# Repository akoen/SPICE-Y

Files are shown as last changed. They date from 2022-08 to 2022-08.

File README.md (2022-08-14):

# SPICE-Y: 2nd Place 2022 ENPH 253 Competition Robot 

  





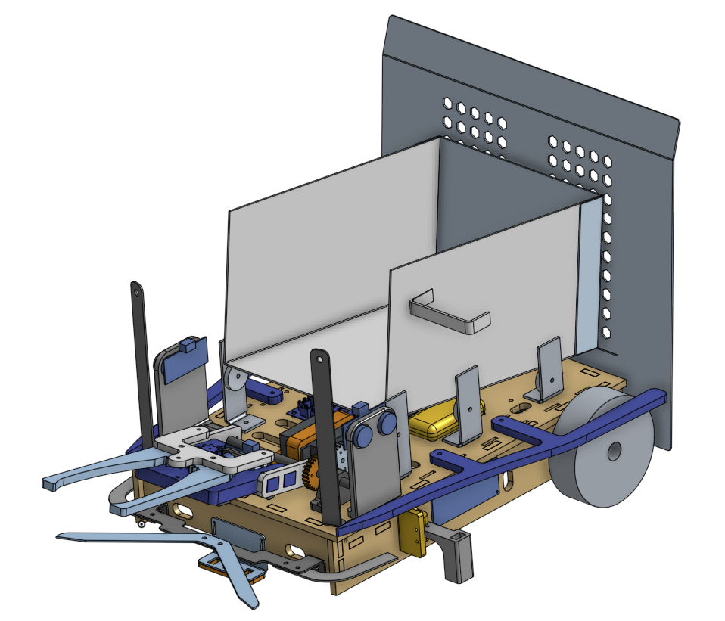
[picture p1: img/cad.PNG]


## Overview & Highlights
- Built on the STM32F103 platform with the [stm32duino](https://github.com/stm32duino/Arduino_Core_STM32) library
- High-data rate ADC sampling (~100 kHz) using direct memory access (DMA) to Fourier decompose infrared beacon signals
- Custom [PCBs](https://github.com/akoen/SPICEBot/blob/main/pcbs/SPICEBot.pdf) for motor drivers, reflectance sensors, mainboard distribution
- Mechanical design done in [Onshape](https://cad.onshape.com/documents/5972b9c60e919ab1b13b074c/w/5fe346639d96b627bb4d7038/e/e34fbf874ea22aab1deaf443)

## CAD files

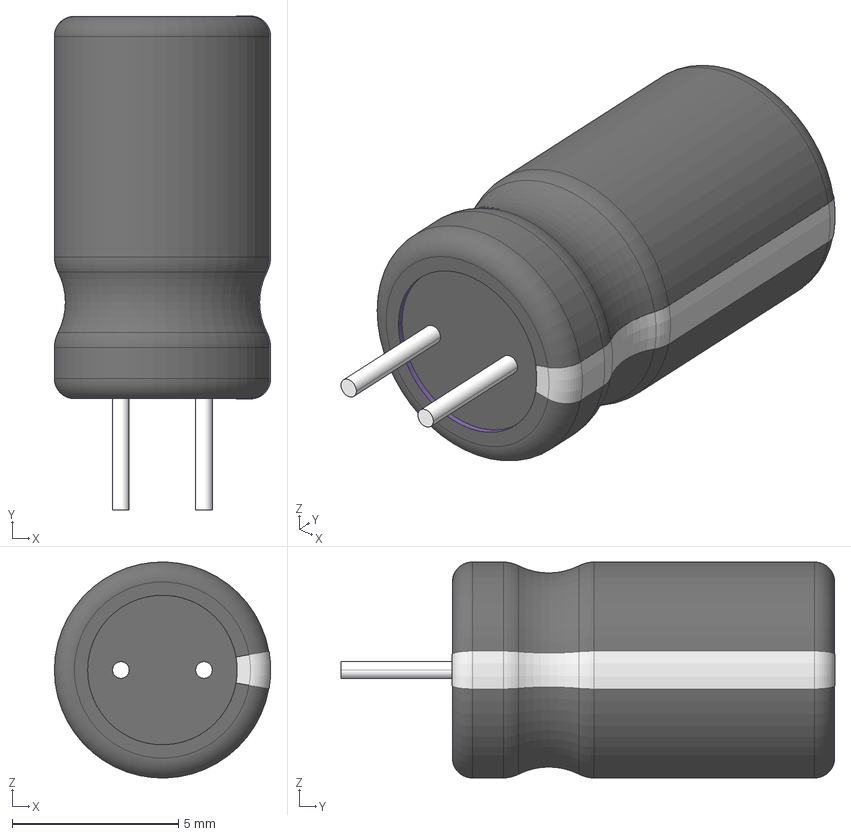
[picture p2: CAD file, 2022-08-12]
pcbs/3D Models/cpol-v_p2-5_d6-5_h11-5.stp
6.50 x 14.9 x 6.50 mm

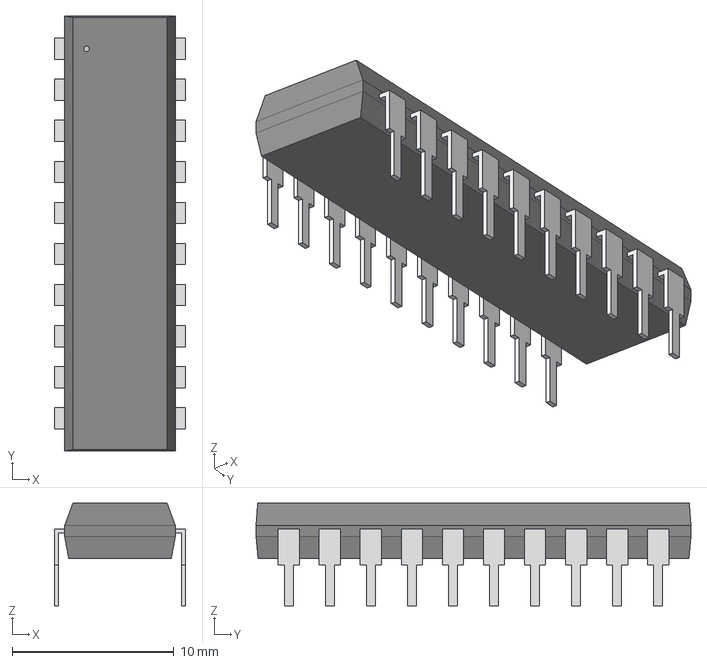
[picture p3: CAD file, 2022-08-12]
pcbs/3D Models/PDIP-20_N_LIT.step
8.13 x 26.9 x 6.35 mm

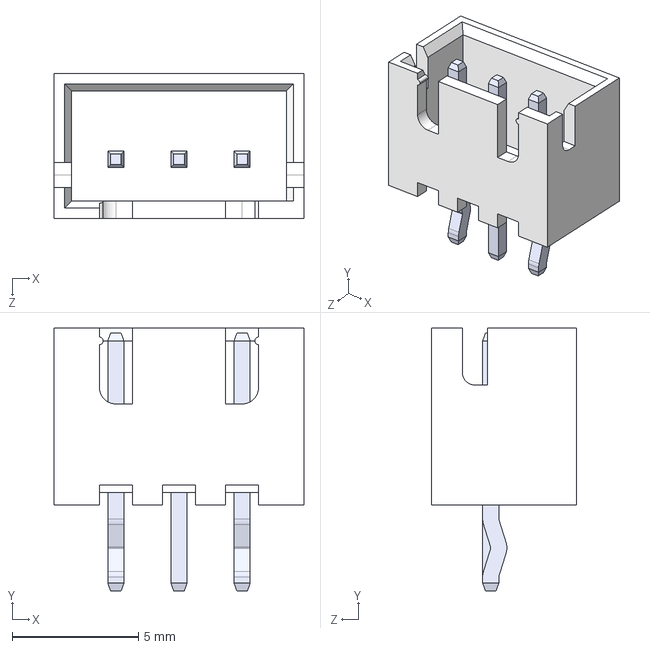
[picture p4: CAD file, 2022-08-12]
pcbs/3D Models/B3B-XH-A-LF--SN---3DModel-STEP-418109.STEP
9.90 x 10.4 x 5.75 mm

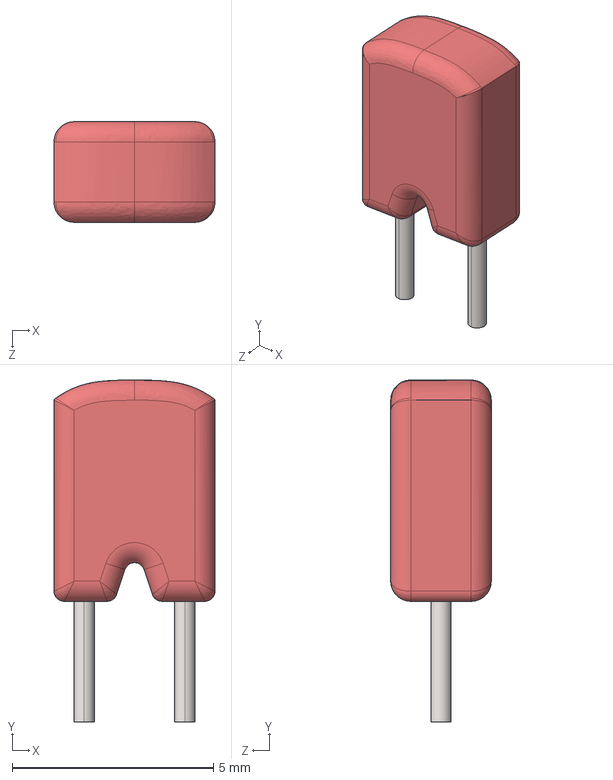
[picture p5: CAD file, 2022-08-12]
pcbs/3D Models/User Library-K104M15X7RF53L2.STEP
4.00 x 8.50 x 2.50 mm

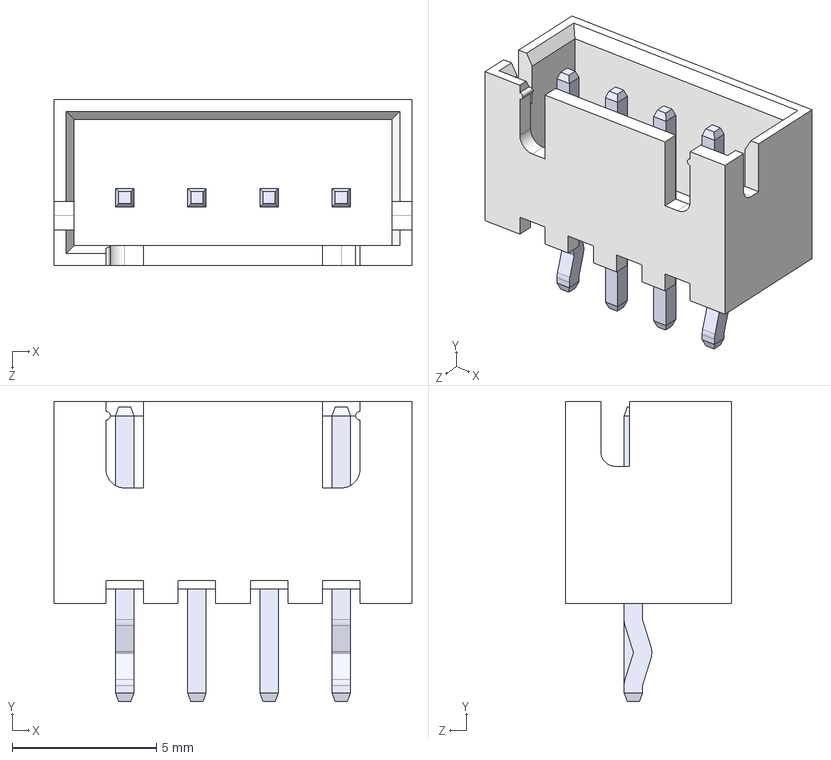
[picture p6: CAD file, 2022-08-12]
pcbs/3D Models/B4B-XH-A-LF--SN---3DModel-STEP-418109.STEP
12.4 x 10.4 x 5.75 mm

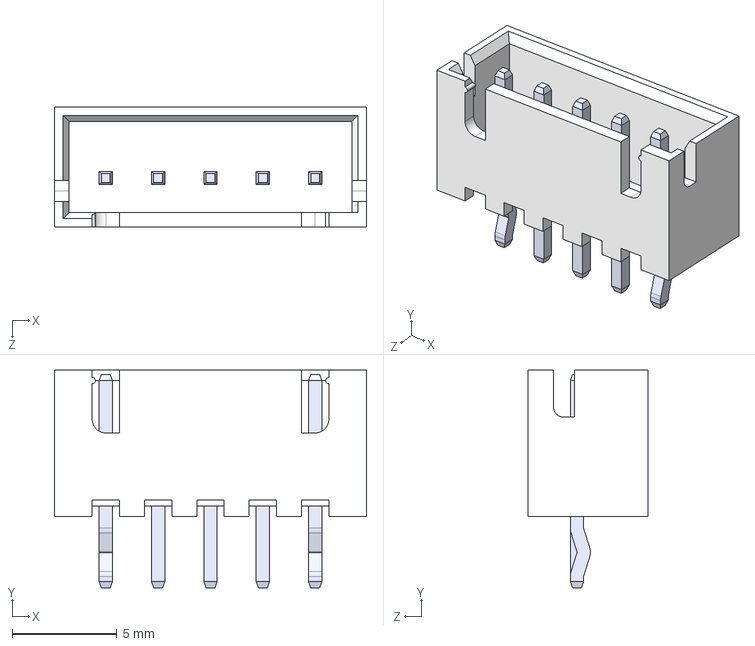
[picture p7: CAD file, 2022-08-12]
pcbs/3D Models/B5B-XH-A-LF--SN---3DModel-STEP-418109.STEP
14.9 x 10.4 x 5.75 mm

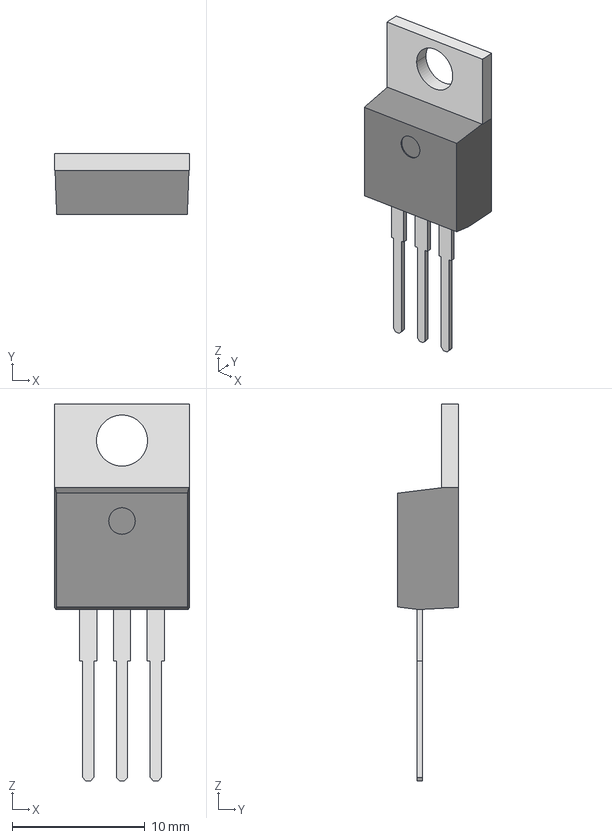
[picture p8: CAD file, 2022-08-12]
pcbs/3D Models/KCS0003B.stp
10.2 x 4.57 x 28.4 mm
BODY-TO-220
LEAD-TO220 x 3
HEATSINK-TO-220

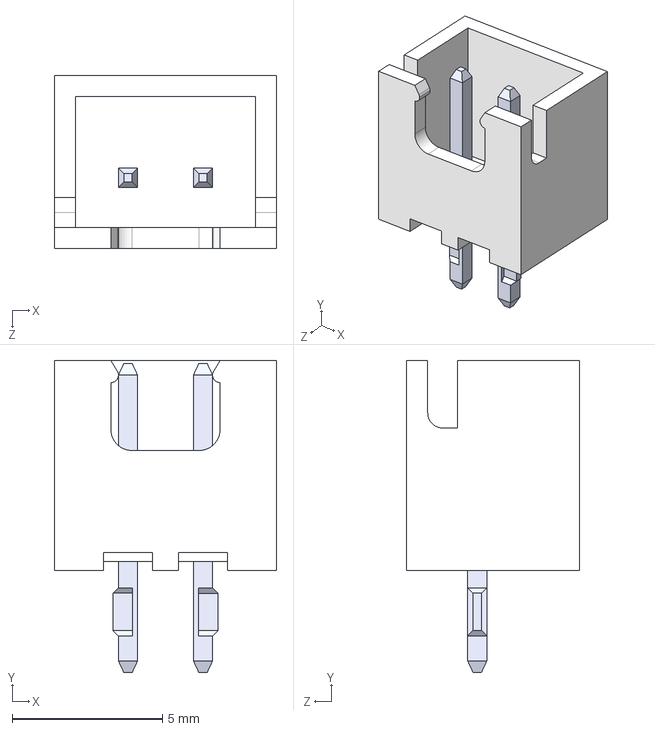
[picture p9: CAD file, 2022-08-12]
pcbs/3D Models/B2B-XH-A-LF--SN---3DModel-STEP-269445.STEP
7.40 x 10.4 x 5.75 mm

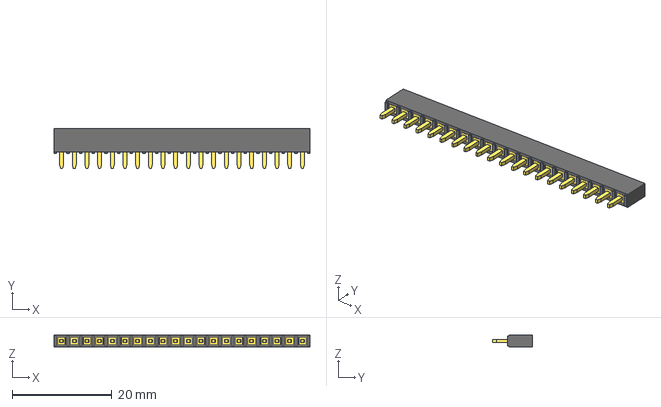
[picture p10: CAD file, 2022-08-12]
pcbs/3D Models/20-Pin Header - Female - 2.54mm.step
51.3 x 8.00 x 2.50 mm

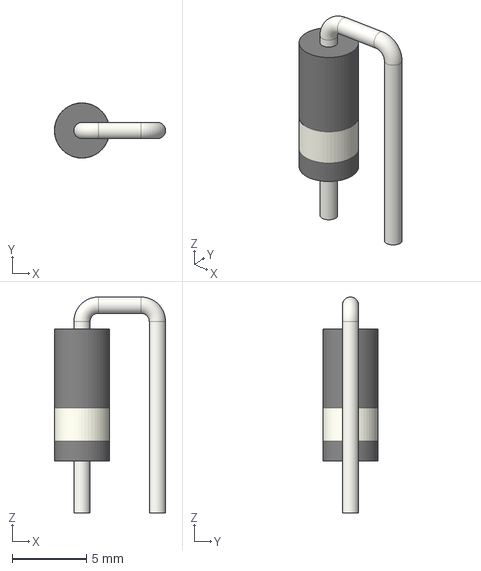
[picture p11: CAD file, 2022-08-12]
pcbs/3D Models/D_5W_P5.08mm_Vertical_AnodeUp.step
7.49 x 3.72 x 14.5 mm

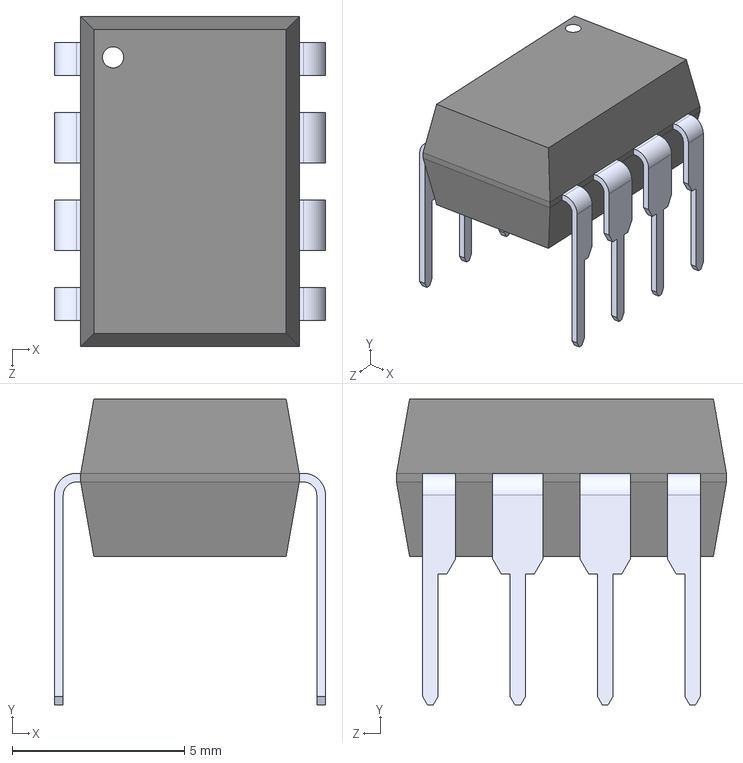
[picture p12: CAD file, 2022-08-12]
pcbs/3D Models/TL082IP.STEP
7.87 x 8.89 x 9.59 mm

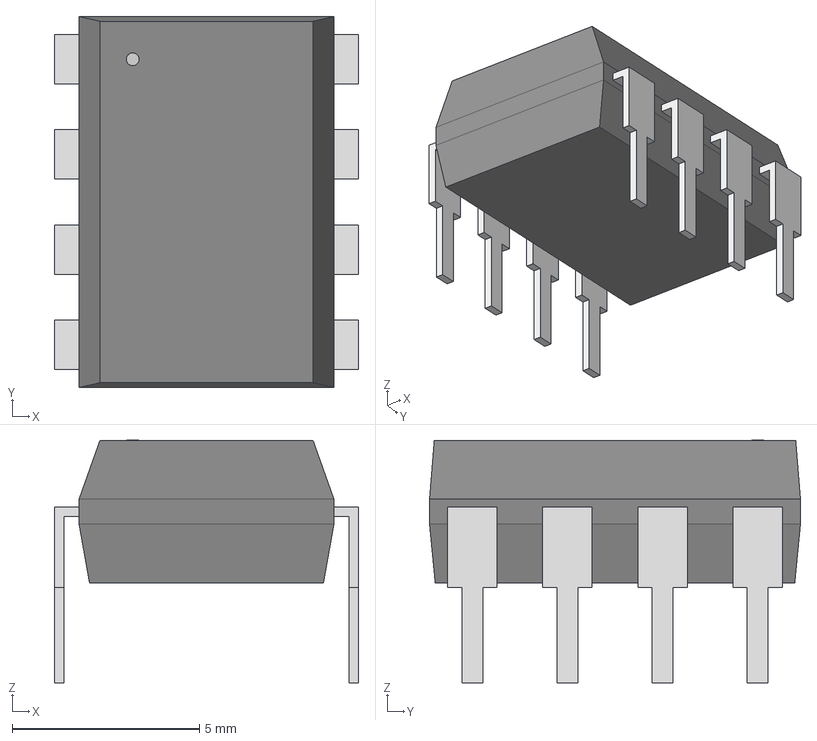
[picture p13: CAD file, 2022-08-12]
pcbs/3D Models/DIP_CT6_VIS.step
8.13 x 9.91 x 6.48 mm

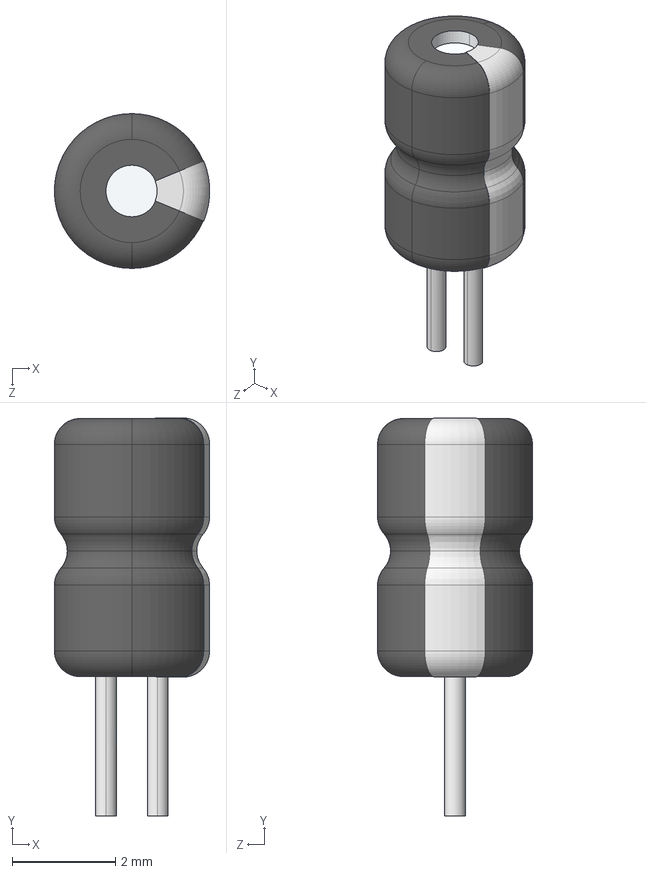
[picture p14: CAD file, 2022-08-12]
pcbs/3D Models/User Library-Capacitor Radial Electrolitic.STEP
3.01 x 7.71 x 3.00 mm

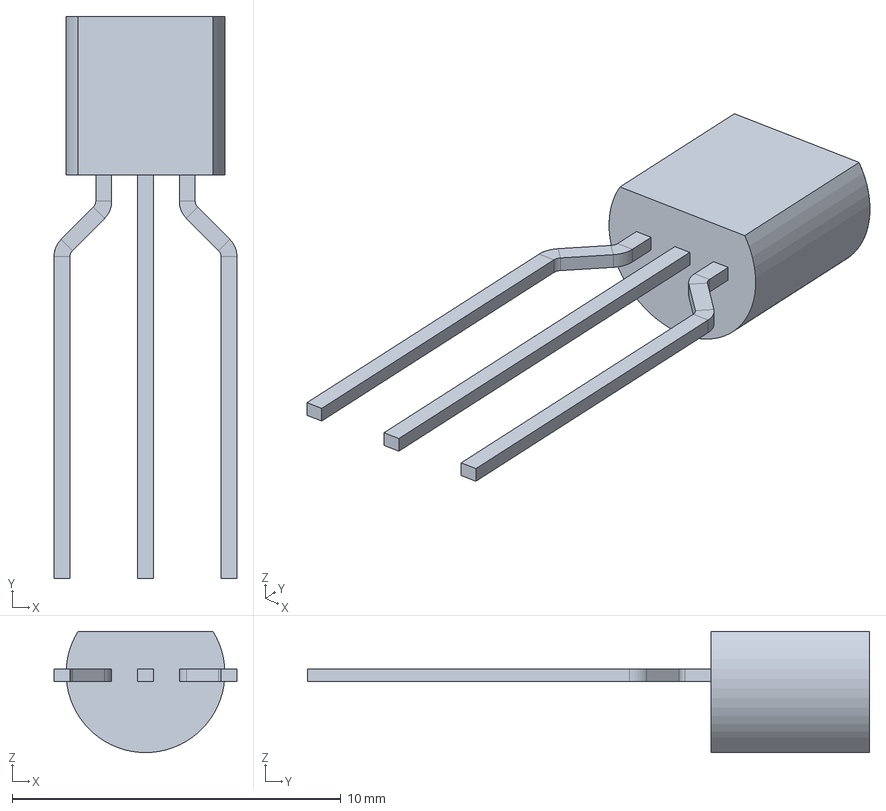
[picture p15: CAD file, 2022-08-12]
pcbs/3D Models/2N2222_1677484790.214.step
5.57 x 17.1 x 3.69 mm
eMachineShop.1
eMachineShop.2
eMachineShop.3
eMachineShop.4
eMachineShop.5
eMachineShop.6
eMachineShop.7
eMachineShop.8
eMachineShop.9
eMachineShop.10
eMachineShop.11
eMachineShop.12
eMachineShop.13
eMachineShop.14
eMachineShop.15
eMachineShop.16
eMachineShop.17
eMachineShop.18
eMachineShop.19
eMachineShop.20
eMachineShop.21
eMachineShop.22
eMachineShop.23
eMachineShop.24
eMachineShop.25
eMachineShop.26
eMachineShop.27
eMachineShop.28
eMachineShop.29
eMachineShop.30
eMachineShop.31
eMachineShop.32
eMachineShop.33
eMachineShop.34
eMachineShop.35
eMachineShop.36
eMachineShop.37
eMachineShop.38
eMachineShop.39
eMachineShop.40
eMachineShop.41
eMachineShop.42
eMachineShop.43
eMachineShop.44
eMachineShop.45
eMachineShop.46
eMachineShop.47
eMachineShop.48
eMachineShop.49
eMachineShop.50
eMachineShop.51
eMachineShop.52
eMachineShop.53
eMachineShop.54
eMachineShop.55

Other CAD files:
pcbs/3D Models/Resistor TH vertical 2,54.stp
pcbs/3D Models/3352T-1-502LF.STEP
pcbs/3D Models/3290W001.stp

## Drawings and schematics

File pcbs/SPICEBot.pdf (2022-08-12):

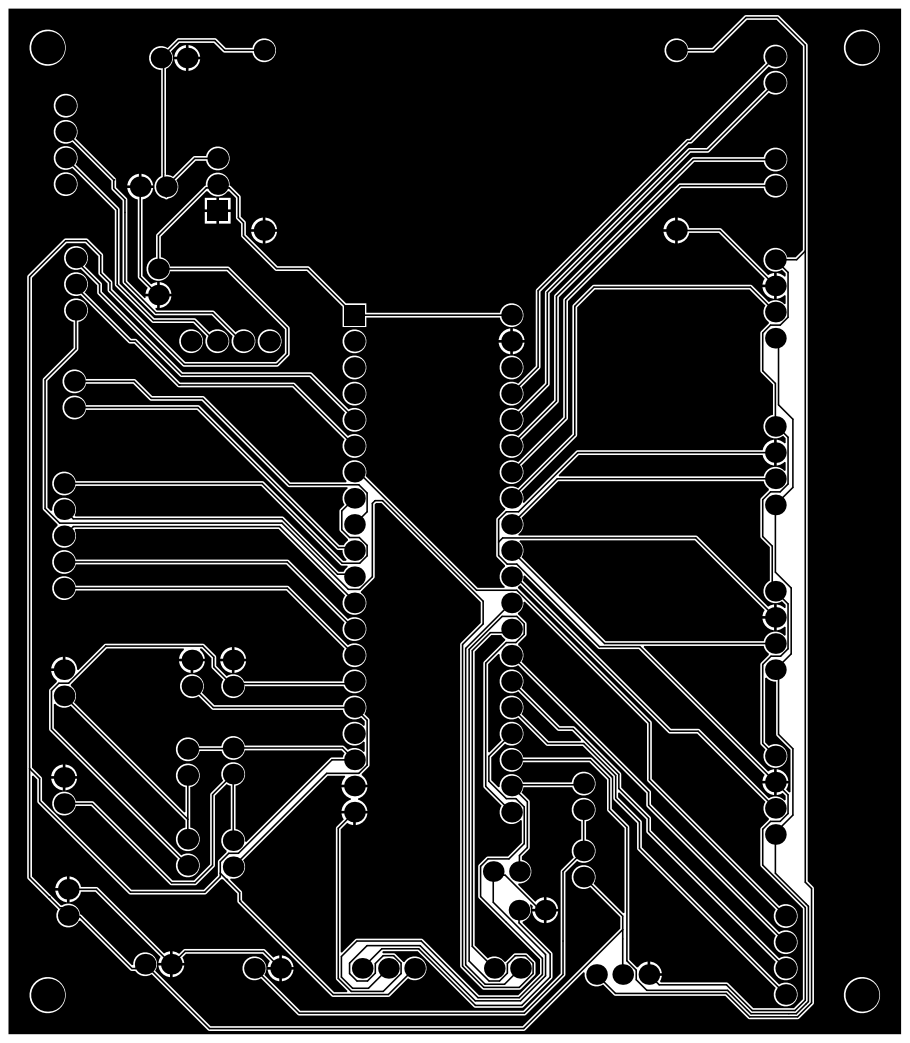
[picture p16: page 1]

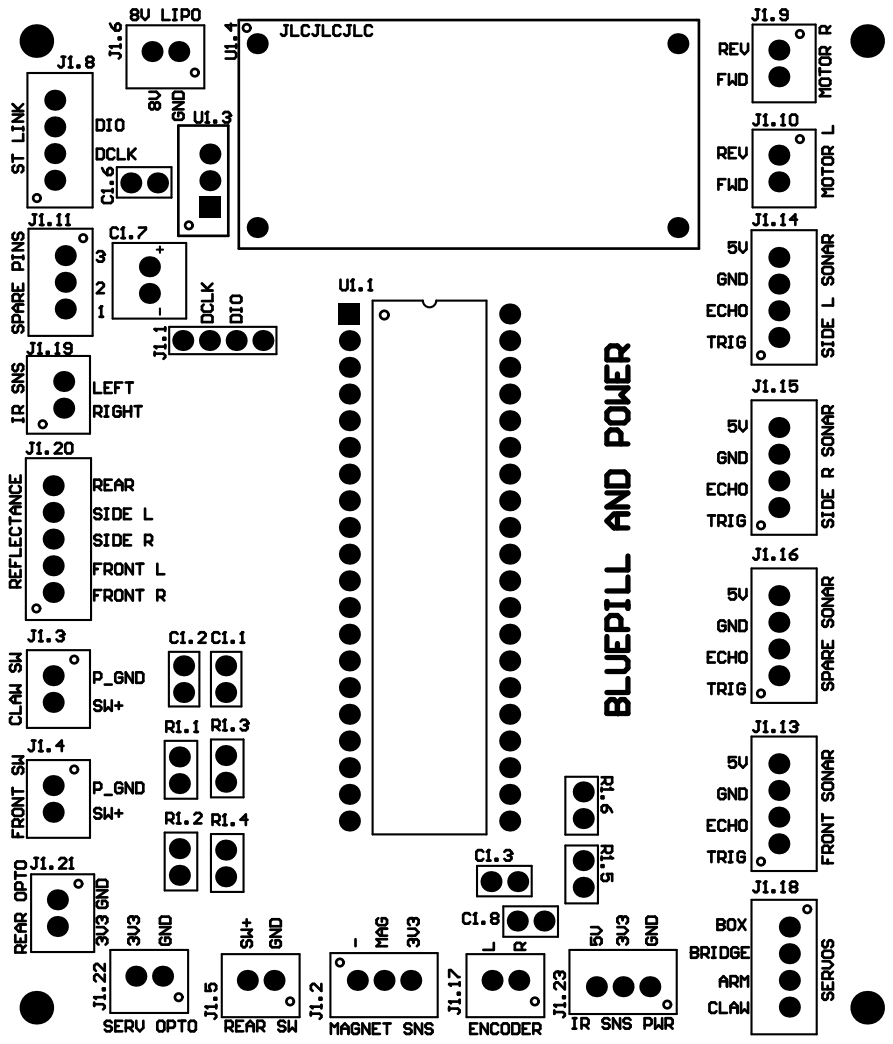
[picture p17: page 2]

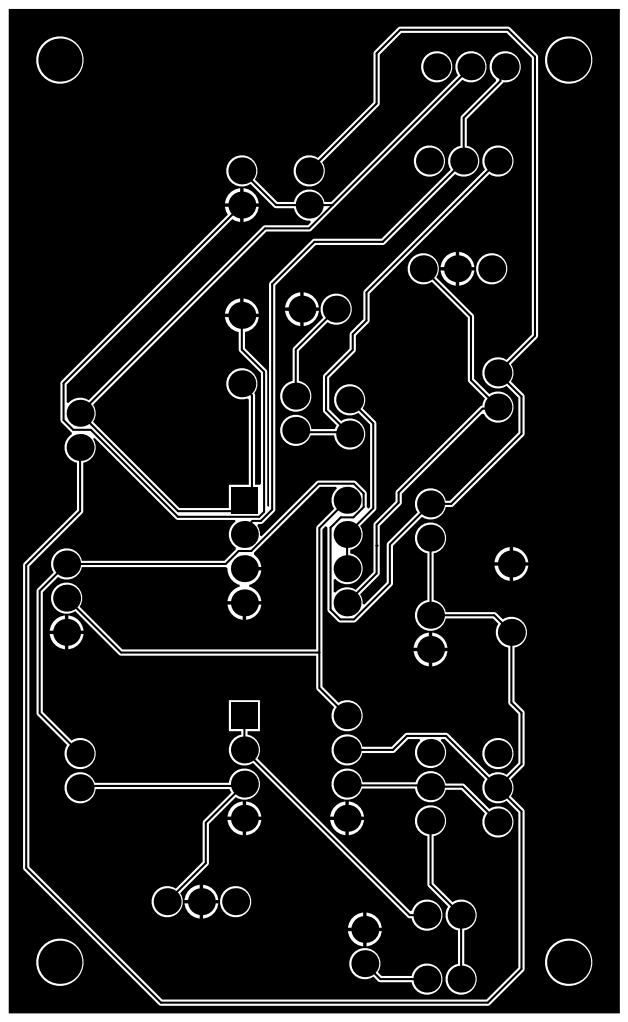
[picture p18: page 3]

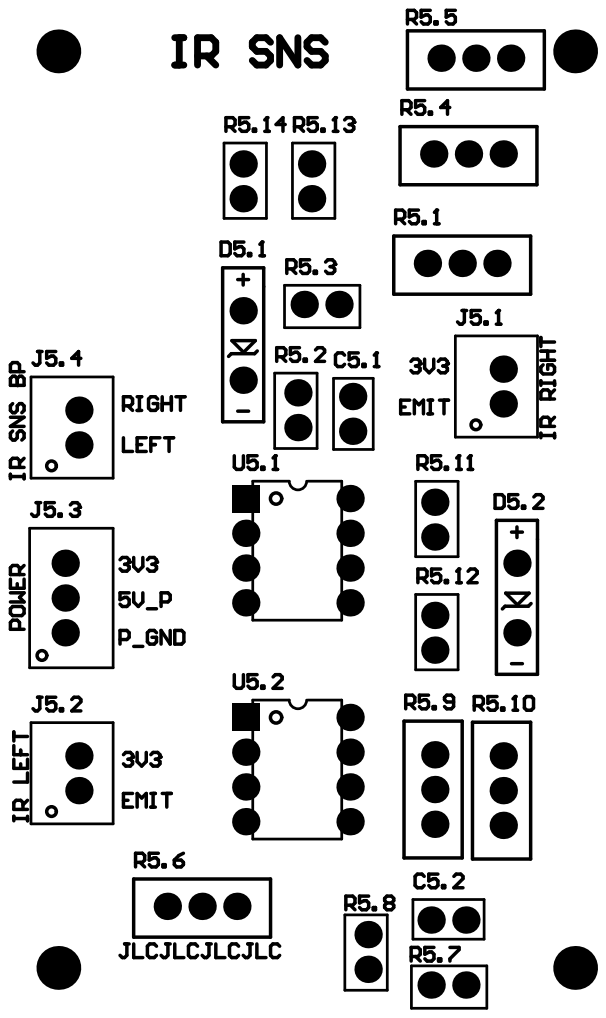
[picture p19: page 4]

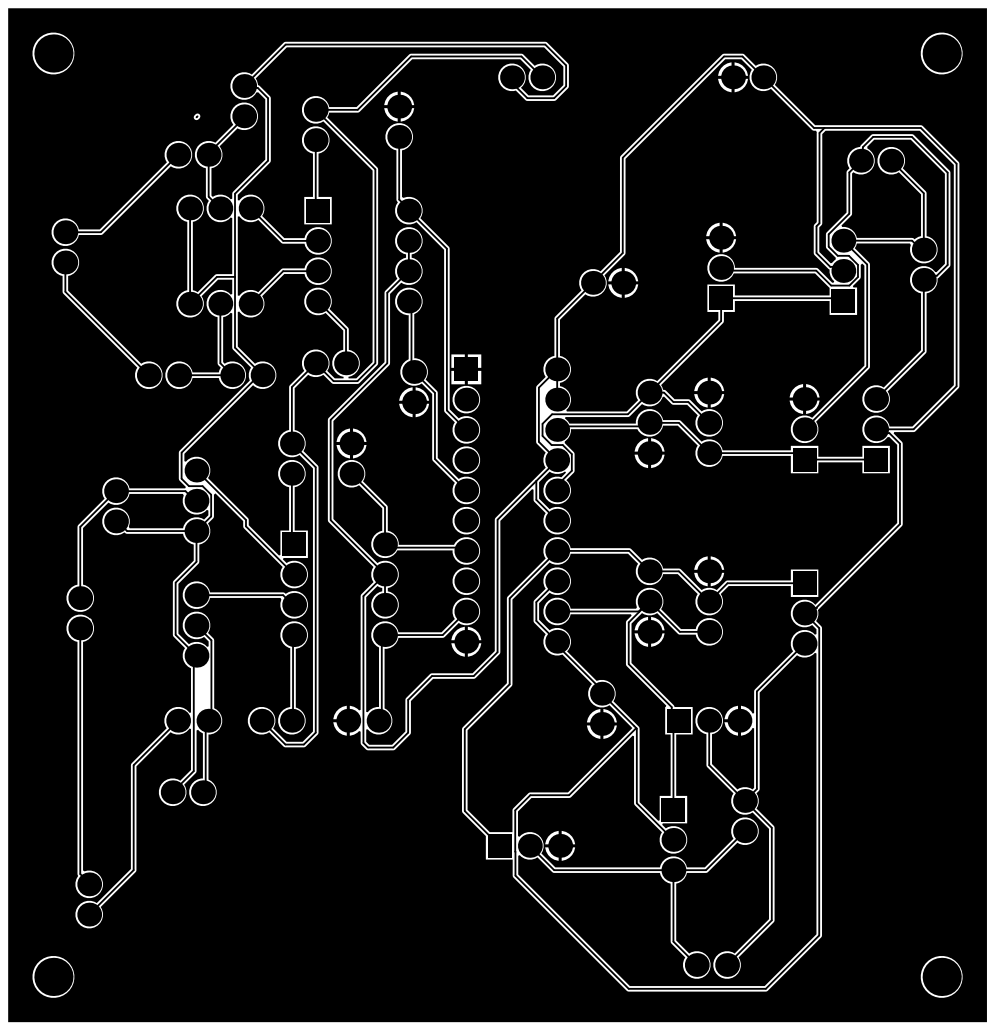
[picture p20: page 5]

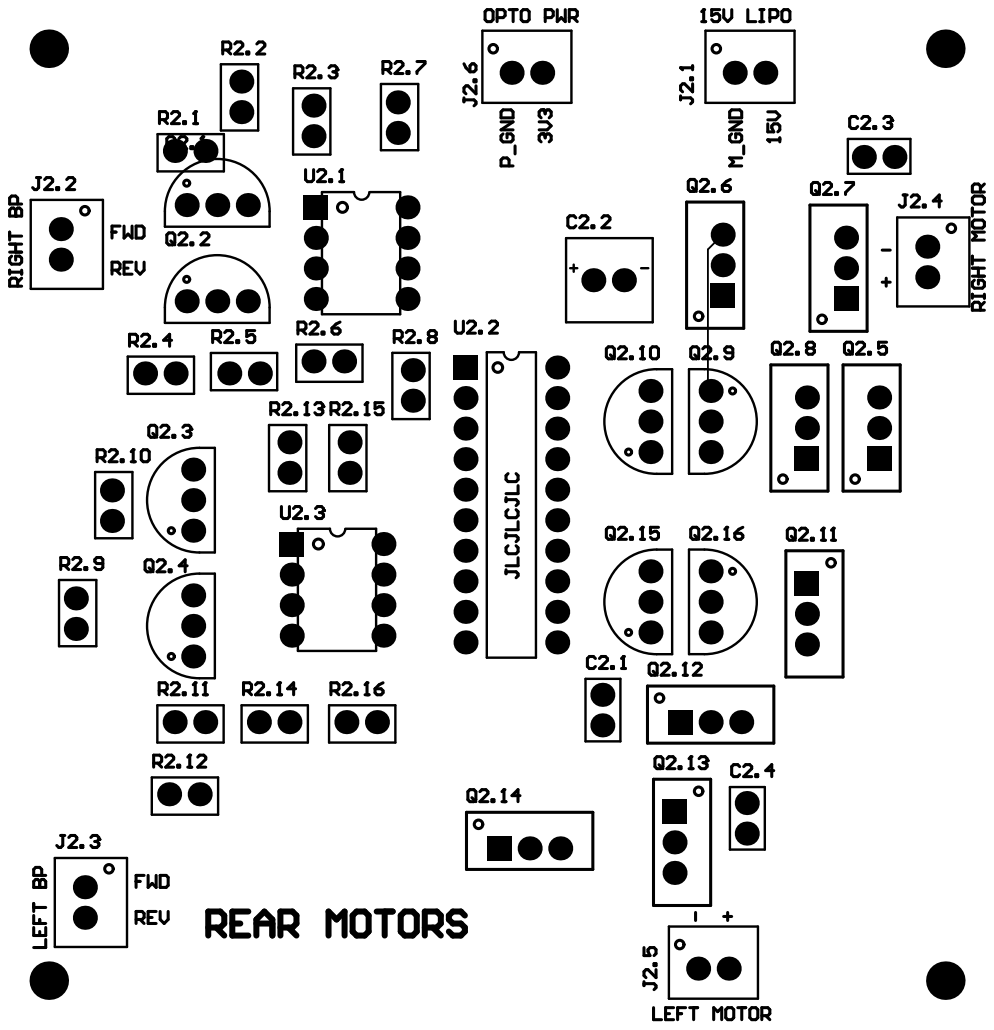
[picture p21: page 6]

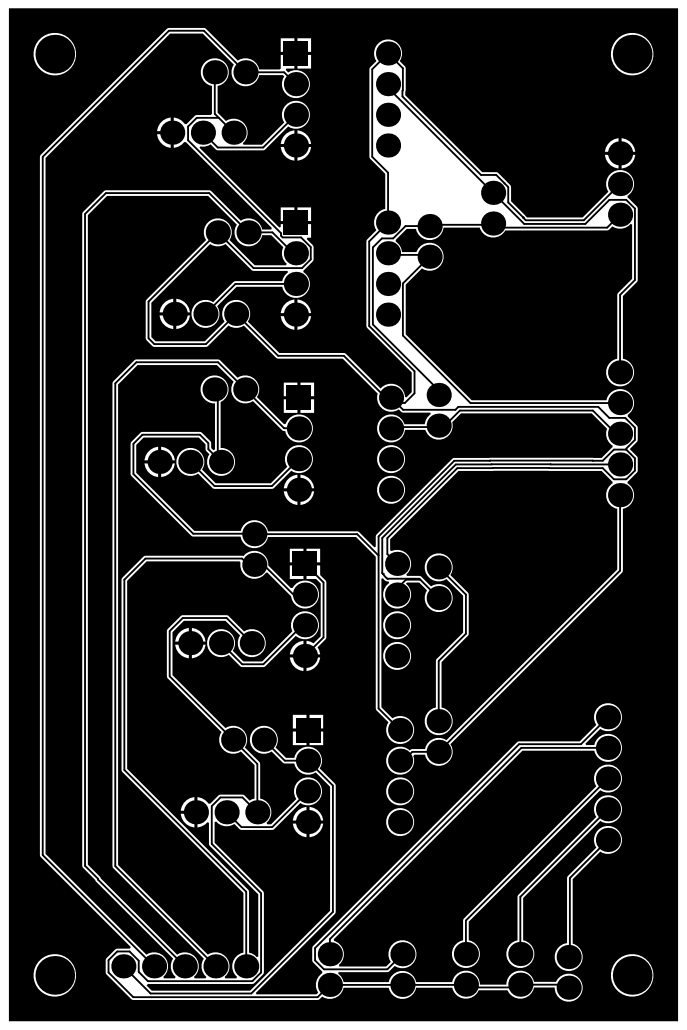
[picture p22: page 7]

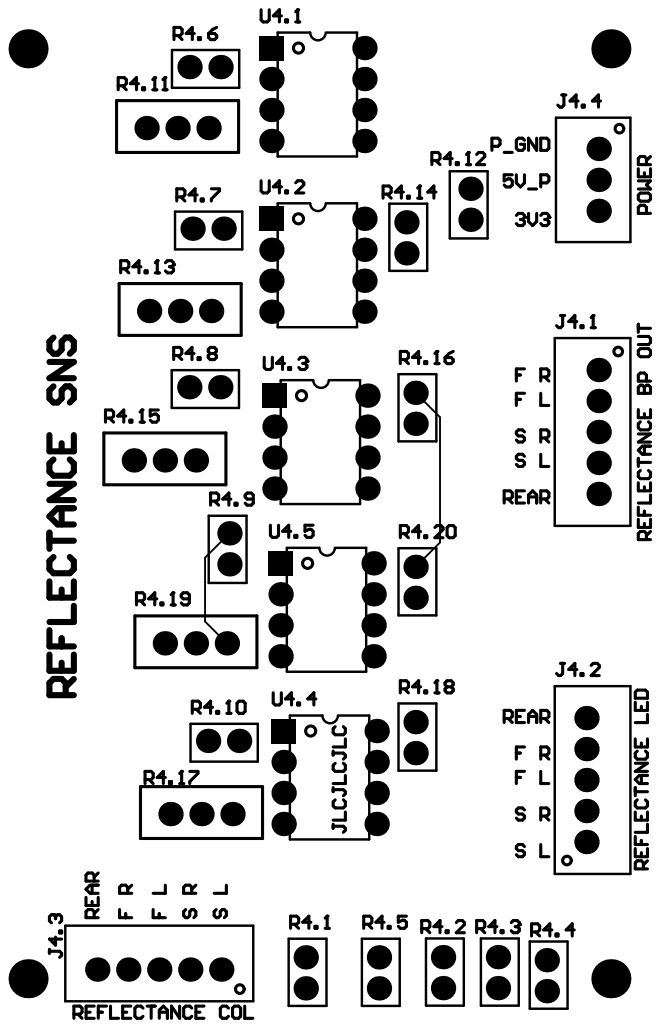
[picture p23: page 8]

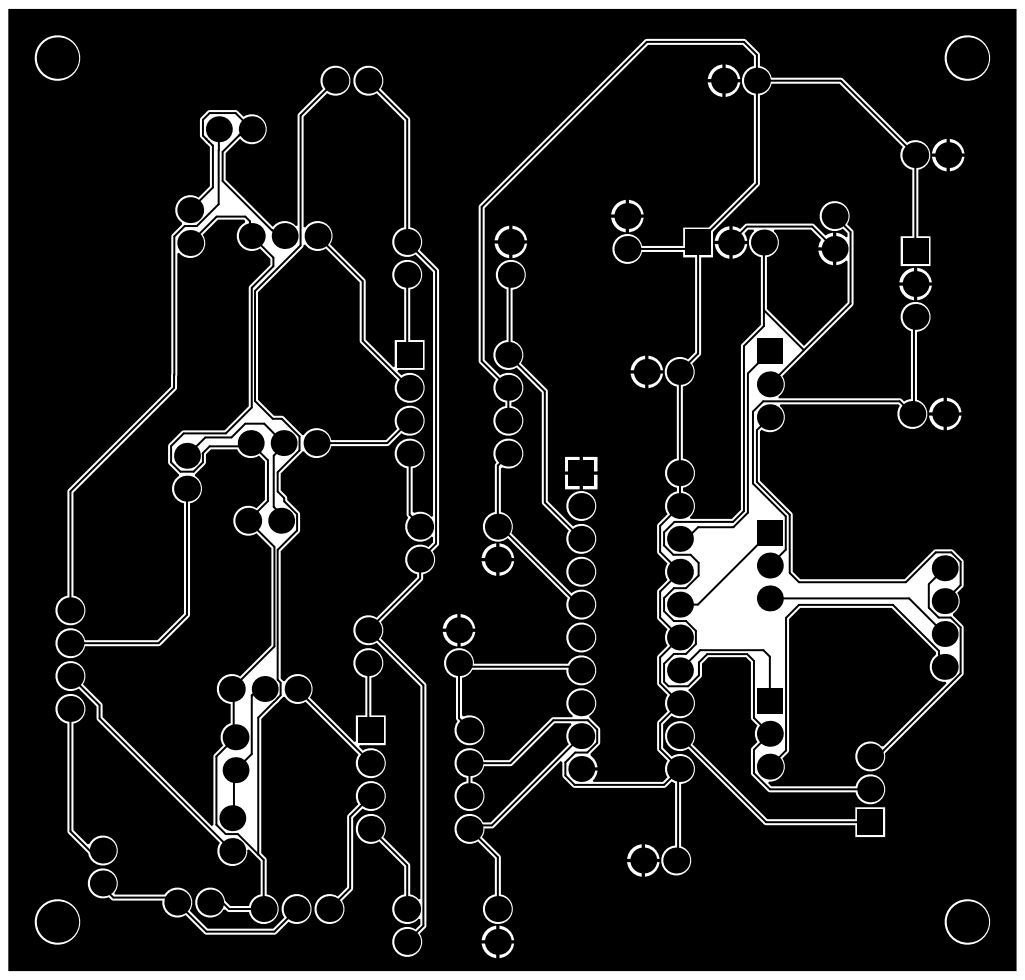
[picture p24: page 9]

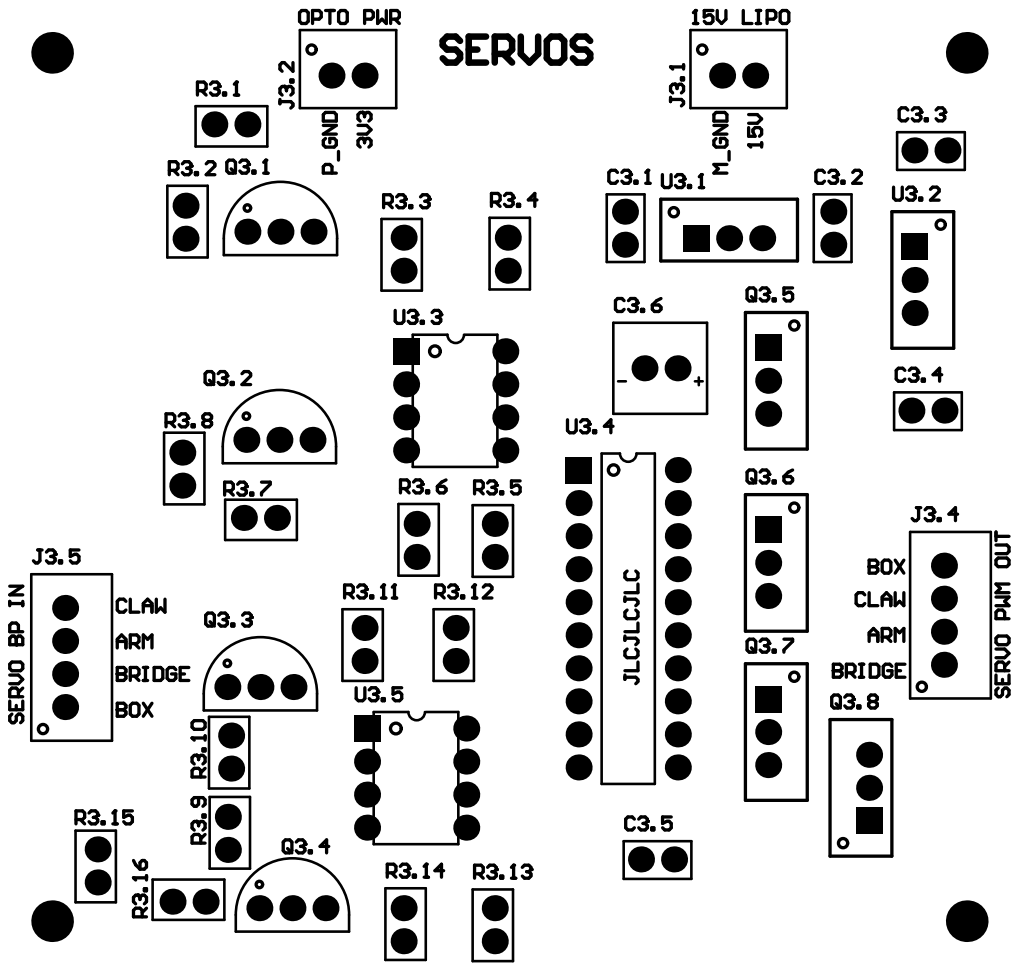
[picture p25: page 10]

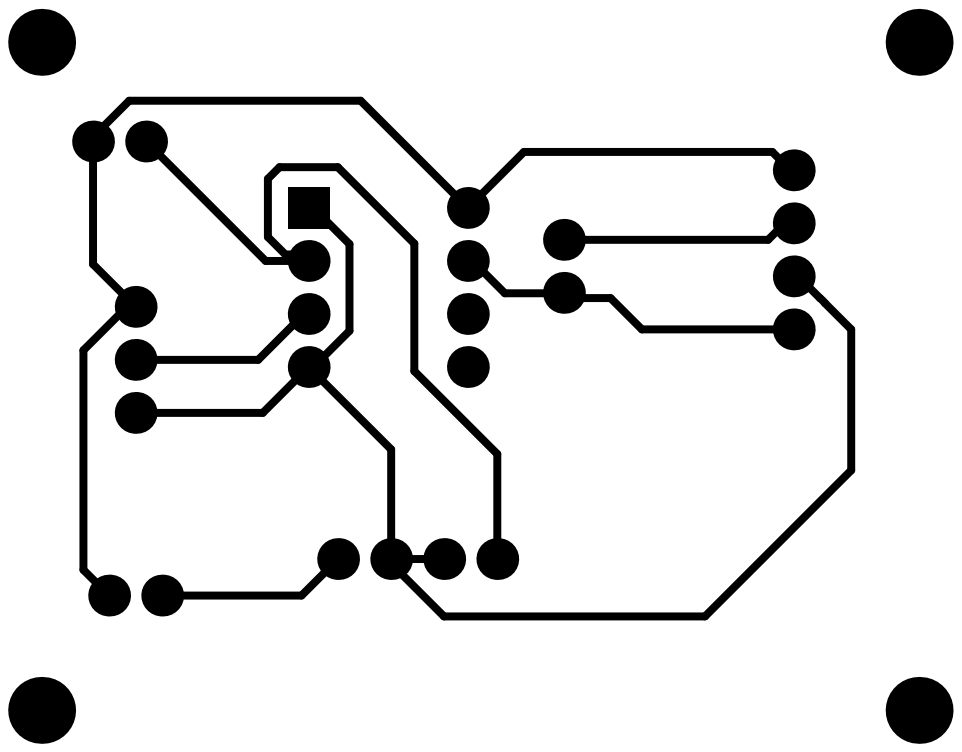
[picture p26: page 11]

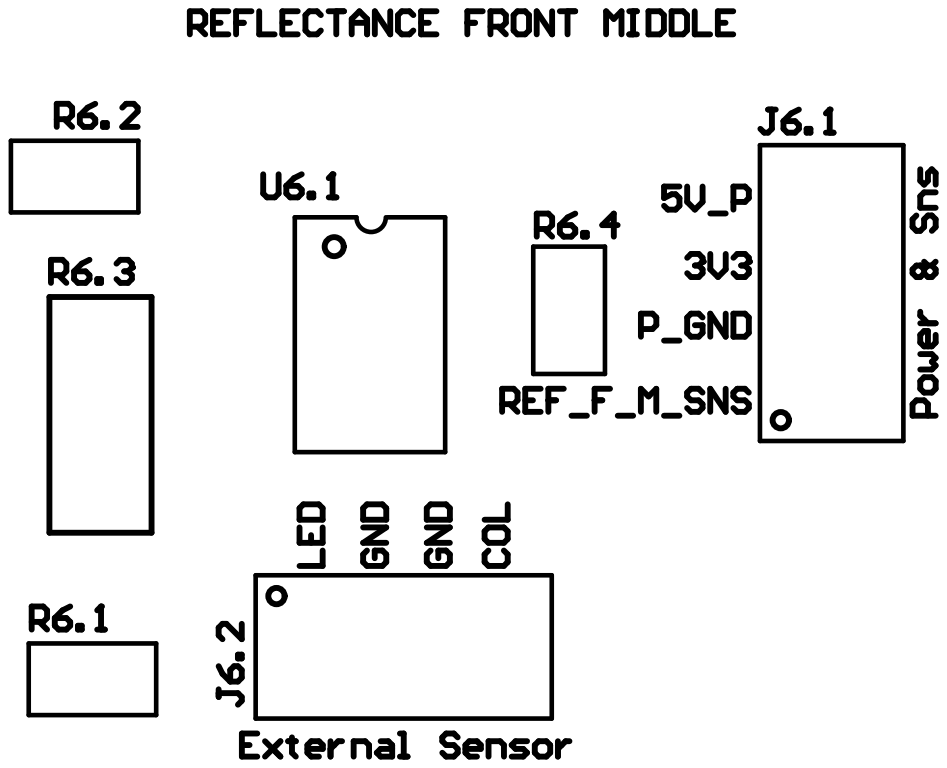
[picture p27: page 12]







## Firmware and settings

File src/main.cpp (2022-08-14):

#include <Arduino.h>
#include <HardwareTimer.h>

#include "motor-driver.h"
#include "tape-follower.h"
#include "encoder.h"
#include "helpers.h"
#include "board-setup.h"
#include "ir.h"
#include "treasure-detection.h"
#include "servo-controller.h"
#include "executor.h"

/* the setup routine runs once when you press reset */
void setup() {
    Serial.begin(115200, SERIAL_8N1);
    Setup::timerHeartbeatInit();
    Setup::ADC();

    Motors::configMotorPins();
    Encoders::configEncoderPins();
    Sonars::configSonarPins();
    ReflectanceSensors::configFrontReflectanceSensors();
    Servos::configAllServoPins();
    
    /* Run the ADC calibration */
    HAL_ADCEx_Calibration_Start(&AdcHandle);
    pinMode(PA12, OUTPUT);
    /* Start ADC conversion on regular group with transfer by DMA */
    // HAL_ADC_Start_DMA(&AdcHandle, (uint32_t *)DMA1Data, IR_SENS_NUM_READINGS);
    Serial.println("Serial connected");
}

void loop() {
    Executor::execute();
    exit(0);
}

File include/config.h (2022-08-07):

#ifndef CONFIG
#define CONFIG

// #include "stm32f1xx_hal_adc.h"
#include <Arduino.h>

#define BLUEPILL_CLOCK_SPEED 72
#define SERIAL_BAUD_RATE 115200

// OLED
#define OLED_SCREEN_WIDTH 128 // OLED display width, in pixels
#define OLED_SCREEN_HEIGHT 64 // OLED display height, in pixels
#define OLED_RESET 	-1 // This display does not have a reset pin accessible

// IR
#define ADC_FAST_SAMPLETIME ADC_SAMPLETIME_71CYCLES_5 // 0.0001/(1/12e6×(71.5+12.5))/2 ~= 7 samples per 10 khz square wave
#define IR_SENS_NUM_READINGS 512
#define IR_SMOOTHING_ALPHA 0.05

/*Pins*/

// motors
# define PWM_MOTOR_FWD_L PB6    
# define PWM_MOTOR_BACK_L PB7

# define PWM_MOTOR_FWD_R PB9
# define PWM_MOTOR_BACK_R PB8

# define PWM_FORMAT_MOTOR_FWD_L PB_6
# define PWM_FORMAT_MOTOR_BACK_L PB_7

# define PWM_FORMAT_MOTOR_FWD_R PB_9
# define PWM_FORMAT_MOTOR_BACK_R PB_8

// encoders
#define R_ENCODER_PIN1 PA0
#define L_ENCODER_PIN1 PA1

// reflectance
# define REFLECTANCE_PIN_R PB1
# define REFLECTANCE_PIN_L PB0
# define REFLECTANCE_PIN_M PA3

# define REFLECTANCE_PIN_SIDE_L PA6 
# define REFLECTANCE_PIN_SIDE_R PA7

// sonar
# define SONAR_TRIG_PIN_ALL PB14

# define SONAR_ECHO_PIN_L PB5
# define SONAR_ECHO_PIN_R PB4
# define SONAR_ECHO_PIN_F PA15

// claw-arm
# define CLAW_SERVO_PIN PA8
# define CLAW_SERVO_PIN_PWM_FORMAT PA_8
# define BRIDGE_SERVO_PIN PA9
# define BRIDGE_SERVO_PIN_PWM_FORMAT PA_9
# define ARM_SERVO_PIN PA10
# define ARM_SERVO_PIN_PWM_FORMAT PA_10
# define BOX_SERVO_PIN PA2
# define BOX_SERVO_PIN_PWM_FORMAT PA_2

// hall effect
# define MAGNETIC_SENSOR_PIN PB15

// switches
# define SWITCH_L 0
# define SIWTCH_R 1

#endif

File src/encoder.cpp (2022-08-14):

#include "encoder.h"

namespace Encoders {
    const double pulse_per_rev = 131 * 1.1;  // divide by counter at end, increases pulse width

    volatile int interruptCountLW = 0;
    volatile int interruptCountRW = 0;
    volatile long pulseLW = 0;
    double posLW = 0;
    volatile long pulseRW = 0;
    double posRW = 0;

    volatile long cacheStartPulse;
    volatile long cacheEndPulse;

    std::stack<std::tuple<Motors::MotorAction, Motors::RotateMode, int, int>*>* cachedActions;     

    bool cacheCreated = false;
    bool cacheAddInProgress = false;

    void ISR_LW() {
        int state1 = digitalRead(L_ENCODER_PIN1);
        if (state1 == 0) {
            // shouldn't occur
            Serial.println("Should not occur");
        } else {    // CCW
            if (Motors::isLWdirFwd) {
                pulseLW++;
            } else {
                pulseLW--;
            }
        } 
        interruptCountLW++;
    }

    void ISR_RW() {
        int state1 = digitalRead(R_ENCODER_PIN1);
        if (state1 == 0) {
            // shouldn't occur
        } else {    // CCW
            if (Motors::isRWdirFwd) {
                pulseRW++;
            } else {
                pulseRW--;
            }
        } 
        interruptCountRW++;
    }

    void attachInterrupts() {
        attachInterrupt(digitalPinToInterrupt(L_ENCODER_PIN1), Encoders::ISR_LW, RISING);
        attachInterrupt(digitalPinToInterrupt(R_ENCODER_PIN1), Encoders::ISR_RW, RISING);
    }

    void configEncoderPins() {
        pinMode(L_ENCODER_PIN1, INPUT);
        pinMode(R_ENCODER_PIN1, INPUT);

        attachInterrupts();
    }

    void detachEncoderInterrupts() {
        detachInterrupt(digitalPinToInterrupt(L_ENCODER_PIN1));
        detachInterrupt(digitalPinToInterrupt(R_ENCODER_PIN1));
    }

    void resetEncoderVals() {
        interruptCountLW = 0;
        interruptCountRW = 0;

        pulseLW = 0;
        posLW = 0;

        pulseRW = 0;
        posRW = 0;
    }

    bool startAddActionCache(Motors::MotorAction motorAction, Motors::RotateMode rotateMode, int dutyCycle) {
        // bad input
        if ((motorAction == Motors::MotorAction::DRIVE_BACK || motorAction == Motors::MotorAction::DRIVE_FWD) && rotateMode != Motors::RotateMode::NONE) {
            return false;
        }
        if ((motorAction == Motors::MotorAction::ROTATE_LEFT || motorAction == Motors::MotorAction::ROTATE_RIGHT) && rotateMode == Motors::RotateMode::NONE) {
            return false;
        }
        if (cacheAddInProgress) return false;

        if (!cacheCreated) {
            cachedActions = new std::stack<std::tuple<Motors::MotorAction, Motors::RotateMode, int, int>*>();
            cacheCreated = true;
        } 
        std::tuple<Motors::MotorAction, Motors::RotateMode, int, int>* tuplePtr = 
        new std::tuple<Motors::MotorAction, Motors::RotateMode, int, int>(motorAction, rotateMode, dutyCycle, 0);
        cachedActions->push(tuplePtr);
        
        switch (motorAction) {
            case Motors::MotorAction::DRIVE_FWD:
            case Motors::MotorAction::DRIVE_BACK:
                cacheStartPulse = pulseRW;  // pulses travelled for LW RW should be same (ideally - if wheels rotate at same speed at given duty cycle)
                break;
            case Motors::MotorAction::ROTATE_LEFT:
            case Motors::MotorAction::ROTATE_RIGHT:
                switch(rotateMode) {
                    case Motors::RotateMode::BACKWARDS:
                        if (motorAction == Motors::MotorAction::ROTATE_LEFT) {
                            // LW moves
                            cacheStartPulse = pulseLW;
                        } else {
                            // RW moves 
                            cacheStartPulse = pulseRW; 
                        }
                        break;
                    case Motors::RotateMode::FORWARDS:
                        if (motorAction == Motors::MotorAction::ROTATE_LEFT) {
                            // RW moves
                            cacheStartPulse = pulseRW;
                        } else {
                            // LW moves 
                            cacheStartPulse = pulseLW; 
                        }
                        break;
                    case Motors::RotateMode::BOTH_WHEELS:
                        // LW, RW moves - ideally same for given duty cycle
                        cacheStartPulse = pulseRW;
                        break;
                }
                break;
        }
        cacheAddInProgress = true;

        return true;
    }

    bool endAddActionCache() {
        if (!cacheCreated || !cacheAddInProgress) return false;
        Motors::MotorAction motorAction = std::get<0>(*cachedActions->top());
        Motors::RotateMode rotateMode = std::get<1>(*cachedActions->top());;
        
        switch (motorAction) {
            case Motors::MotorAction::DRIVE_FWD:
            case Motors::MotorAction::DRIVE_BACK:
                cacheEndPulse = pulseRW;  // pulses travelled for LW RW should be same (ideally - if wheels rotate at same speed at given duty cycle)
                break;
            case Motors::MotorAction::ROTATE_LEFT:
            case Motors::MotorAction::ROTATE_RIGHT:
                switch(rotateMode) {
                    case Motors::RotateMode::BACKWARDS:
                        if (motorAction == Motors::MotorAction::ROTATE_LEFT) {
                            // LW moves
                            cacheEndPulse = pulseLW;
                        } else {
                            // RW moves 
                            cacheEndPulse = pulseRW; 
                        }
                        break;
                    case Motors::RotateMode::FORWARDS:
                        if (motorAction == Motors::MotorAction::ROTATE_LEFT) {
                            // RW moves
                            cacheEndPulse = pulseRW;
                        } else {
                            // LW moves 
                            cacheEndPulse = pulseLW; 
                        }
                        break;
                    case Motors::RotateMode::BOTH_WHEELS:
                        // LW, RW moves - ideally same for given duty cycle
                        cacheEndPulse = pulseRW;
                        break;
                }
                break;
        }
        std::get<3>(*cachedActions->top()) = abs(cacheEndPulse - cacheStartPulse);

        cacheAddInProgress = false;

        return true;
    }

    bool executeReverseCache(int actionDelayMillis) {
        if (!cacheCreated || cacheAddInProgress) return false;
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

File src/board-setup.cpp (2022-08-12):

/* Credit to fpiSTM on the stm32duino forums for the only working HAL DMA
   example on the internet: https://www.stm32duino.com/viewtopic.php?t=110 */

#include <HardwareTimer.h>

#include <board-setup.h>
#include <config.h>

ADC_HandleTypeDef AdcHandle;
uint16_t DMA1Data[IR_SENS_NUM_READINGS];
bool DMA1DataAvailable = false;

HardwareTimer timerHeartbeat(TIM1);


namespace Setup {
    bool ledOn = false;
    
    void timerHeartbeatInterrupt() {
        ledOn = !ledOn;
        digitalWrite(LED_BUILTIN, ledOn ? HIGH : LOW);
        digitalWrite(PB2, ledOn ? HIGH : LOW);
    }

    void timerHeartbeatInit() {
        timerHeartbeat.setOverflow(2, HERTZ_FORMAT);
        timerHeartbeat.attachInterrupt(timerHeartbeatInterrupt);
        timerHeartbeat.resume();
    }

/**
    @brief  ADC configuration
    @param  None
    @retval None
*/
    void ADC() {
        ADC_ChannelConfTypeDef sConfig;

        /* Configuration of ADCx init structure: ADC parameters and regular group */
        AdcHandle.Instance = ADC1;
        AdcHandle.Init.DataAlign = ADC_DATAALIGN_RIGHT;
        AdcHandle.Init.ScanConvMode = ADC_SCAN_ENABLE;                  /* Sequencer disabled (ADC conversion on only 1 channel: channel set on rank 1) */
        AdcHandle.Init.ContinuousConvMode = ENABLE;                    /* Continuous mode to have maximum conversion speed (no delay between conversions) */
        AdcHandle.Init.NbrOfConversion = 2;                             /* Parameter discarded because sequencer is disabled */
        AdcHandle.Init.DiscontinuousConvMode = DISABLE;                 /* Parameter discarded because sequencer is disabled */
        AdcHandle.Init.NbrOfDiscConversion = 1;                         /* Parameter discarded because sequencer is disabled */
        AdcHandle.Init.ExternalTrigConv = ADC_SOFTWARE_START;            /* Software start to trig the 1st conversion manually, without external event */

        if (HAL_ADC_Init(&AdcHandle) != HAL_OK) {
            /* ADC initialization error */
            Error_Handler();
        }

        /* Configuration of channel on ADCx regular group on sequencer rank 1 */
        /* Note: Considering IT occurring after each ADC conversion if ADC          */
        /*       conversion is out of the analog watchdog window selected (ADC IT   */
        /*       enabled), select sampling time and ADC clock with sufficient       */
        /*       duration to not create an overhead situation in IRQHandler.        */
        sConfig.Channel = ADC_CHANNEL_4;
        sConfig.Rank = ADC_REGULAR_RANK_1;
        sConfig.SamplingTime = ADC_FAST_SAMPLETIME;
        HAL_ADC_ConfigChannel(&AdcHandle, &sConfig);

        sConfig.Channel = ADC_CHANNEL_5;
        sConfig.Rank = ADC_REGULAR_RANK_2;
        sConfig.SamplingTime = ADC_FAST_SAMPLETIME;
        HAL_ADC_ConfigChannel(&AdcHandle, &sConfig);
    }
}

extern "C" void SystemClock_Config() {
    RCC_OscInitTypeDef RCC_OscInitStruct = {0};
    RCC_ClkInitTypeDef RCC_ClkInitStruct = {0};
    RCC_PeriphCLKInitTypeDef PeriphClkInit = {0};

    /** Initializes the RCC Oscillators according to the specified parameters
    * in the RCC_OscInitTypeDef structure.
    */
    RCC_OscInitStruct.OscillatorType = RCC_OSCILLATORTYPE_HSE;
    RCC_OscInitStruct.HSEState = RCC_HSE_ON;
    RCC_OscInitStruct.HSEPredivValue = RCC_HSE_PREDIV_DIV1;
    RCC_OscInitStruct.HSIState = RCC_HSI_ON;
    RCC_OscInitStruct.PLL.PLLState = RCC_PLL_ON;
    RCC_OscInitStruct.PLL.PLLSource = RCC_PLLSOURCE_HSE;
    RCC_OscInitStruct.PLL.PLLMUL = RCC_PLL_MUL9;
    if (HAL_RCC_OscConfig(&RCC_OscInitStruct) != HAL_OK) {
        Error_Handler();
    }

    /** Initializes the CPU, AHB and APB buses clocks
    */
    RCC_ClkInitStruct.ClockType = RCC_CLOCKTYPE_HCLK | RCC_CLOCKTYPE_SYSCLK
                                  | RCC_CLOCKTYPE_PCLK1 | RCC_CLOCKTYPE_PCLK2;
    RCC_ClkInitStruct.SYSCLKSource = RCC_SYSCLKSOURCE_PLLCLK;
    RCC_ClkInitStruct.AHBCLKDivider = RCC_SYSCLK_DIV1;
    RCC_ClkInitStruct.APB1CLKDivider = RCC_HCLK_DIV2;
    RCC_ClkInitStruct.APB2CLKDivider = RCC_HCLK_DIV1;

    if (HAL_RCC_ClockConfig(&RCC_ClkInitStruct, FLASH_LATENCY_2) != HAL_OK) {
        Error_Handler();
    }
    PeriphClkInit.PeriphClockSelection = RCC_PERIPHCLK_ADC;
    PeriphClkInit.AdcClockSelection = RCC_ADCPCLK2_DIV6;
    if (HAL_RCCEx_PeriphCLKConfig(&PeriphClkInit) != HAL_OK) {
        Error_Handler();
    }
}

/**
    @brief  This function handles ADC interrupt request.
    @param  None
    @retval None
*/
extern "C" void ADC1_2_IRQHandler(void) {
    HAL_ADC_IRQHandler(&AdcHandle);
}

/**
  @brief  This function handles DMA interrupt request.
  @param  None
  @retval None
*/
extern "C" void DMA1_Channel1_IRQHandler(void) {
    HAL_DMA_IRQHandler(AdcHandle.DMA_Handle);
}
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

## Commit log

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2022-06-19 Added Altium project files
    [Main.SchDoc, SPICEBot.PrjPcb, SPICEBot_SchLib.SchLib]
2022-06-20 Motor driver circuits for rear wheels
    [Main.SchDoc, SPICEBot_SchLib.SchLib]
2022-06-20 Added IR filtering SPICE sim
    [Main.SchDoc]
2022-06-20 Updated refdes on filter circuit
    [Main.SchDoc]
2022-06-21 Added bluepill pinout excel
    [Bluepill Pinout SPICEBot.xlsx]
2022-06-21 updated filtering circuit
    [Bluepill Pinout SPICEBot.xlsx]
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2022-06-27 Sonar code, pulseIn() issues
    [main.cpp]
2022-07-04 Added second motor circuit, need to rename nets
    [Main.SchDoc]
2022-07-04 Updated Altium
    [SPICEBot.PrjPcb]
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2022-07-05 Separated motor, peripheral schematics
    [Main.SchDoc, Motors.SchDoc, SPICEBot.PrjPcb]
2022-07-05 XTRA Motor Driver in, no GPIOs assigned
    [Main.SchDoc, Motors.SchDoc]
2022-07-05 Completed motor and servo circuits, added microswitch circuits, need res cap values
    [Main.SchDoc, Motors.SchDoc, SPICEBot_SchLib.SchLib]
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2022-07-06 Need to update BP nets
    [Main.SchDoc, SPICEBot.PrjPcb, SPICEBot_SchLib.SchLib]
2022-07-06 Completed peripheral and motor schematic
    [Main.SchDoc, Motors.SchDoc, SPICEBot_SchLib.SchLib]
2022-07-06 Added motor, main pcb, created pcblib
    [Main.PcbDoc, Motor.PcbDoc, SPICEBot_PCBLib.PcbLib]
2022-07-06 Added cap footprint
    [SPICEBot_PCBLib.PcbLib, SPICEBot_SchLib.SchLib, User Library-CAP-CER-DISC5.STEP]
2022-07-06 Footprints for connectors, DIP8, res, cap
    [B2B-XH-A-LF--SN---3DModel-STEP-269445.STEP, B3B-XH-A-LF--SN---3DModel-STEP-418109.STEP, B4B-XH-A-LF--SN---3DModel-STEP-418109.STEP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]
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2022-07-06 Finalized schematic adnd footprints, need BP footprint
    [3290W001.stp, CircuitWorks-DIODE0_4.STEP, KCS0003B.stp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]
2022-07-07 Completed all footprints
    [Main.SchDoc]
2022-07-07 New BP symbol and footprint, std metric tht sizes
    [20-Pin Header - Female - 2.54mm.step, Main.SchDoc, Motors.SchDoc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]
2022-07-07 BP debug conn symbol and footprint
    [Main.SchDoc, SPICEBot_PCBLib.PcbLib, SPICEBot_SchLib.SchLib]
2022-07-08 buffer for IR circuit
    [Main.SchDoc]
2022-07-08 Comparators for reflectance sensors
    [Front Motors.PcbDoc, Main.SchDoc, Motors.SchDoc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]
2022-07-08 Cleaned up 3d models, standard tht and pad sizes
    [2N2222_1677484790.214.step, BP and Sensors.PcbDoc, CPF1_VIS.step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]
2022-07-08 Schematic and footprints compile no errors
    [BP and Sensors.PcbDoc, Main.SchDoc, Motors and Servos.PcbDoc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]
2022-07-08 started layout of BP board
    [BP and Sensors.PcbDoc, Main.SchDoc, Motors and Servos.PcbDoc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]
2022-07-08 updated layout began routing
    [BP and Sensors.PcbDoc, Main.SchDoc]
2022-07-08 BP and Sensor board done pending DR
    [SPICEBot.PrjPcb]
2022-07-09 updated pcb for bluepill, layed out motor PCB
    [Main.SchDoc, Motors and Servos.PcbDoc, Motors.SchDoc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]
2022-07-10 Split schematics into several
    [(OLD) BP and Sensors.PcbDoc, (OLD) Main.SchDoc, (OLD) Motors and Servos.PcbDoc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]
2022-07-10 Separated all schematics
    [(OLD) BP and Sensors.PcbDoc, (OLD) Main.SchDoc, (OLD) Motors and Servos.PcbDoc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]
2022-07-10 Fixed schematic complilation error
    [BP.PcbDoc, Bluepill and Power.SchDoc, IR Sensors.PcbDoc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]
2022-07-10 BP schem and PCB finished
    [BP.PcbDoc, Bluepill and Power.SchDoc, SPICEBot.PrjPcb]
2022-07-11 Completed all PCBs
    [IR Sensors.PcbDoc, Rear Motors.PcbDoc, Rear Motors.SchDoc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]
2022-07-11 Final designators, OutJob PDF sucessfully
    [BP.PcbDoc, IR Sensors.PcbDoc, Rear Motors.PcbDoc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]
2022-07-11 outjob works with individual layers
    [SPICEBot.PrjPcb]
2022-07-11 pinout for IRFZ44N and VN22222LL
    [3352T-1-502LF.STEP, BP.PcbDoc, Bluepill and Power.SchDoc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]
2022-07-12 resized boards, updated IR analog circuit
    [BP.PcbDoc, IR Sensors.PcbDoc, IR Sensors.step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]
2022-07-12 gerbers and drill files in output files
    [BP.PcbDoc, Rear Motors.PcbDoc, SPICEBot.PrjPcb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]
2022-07-13 comments on schs
    [Bluepill and Power.SchDoc, Reflectance.SchDoc, SPICEBot.PrjPcb]
2022-07-13 reflectance pcb 5V, BP 3.3V regulator pinout
    [BP.PcbDoc, Bluepill and Power.SchDoc, IR Sensors.step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]
2022-07-14 single reflectance sensor board)
    [Bluepill and Power.SchDoc, Reflectance (Single).PcbDoc, Reflectance (Single).SchDoc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]
2022-07-14 silkscreen changes
    [Reflectance (Single).PcbDoc, SPICEBot.PrjPcb]
2022-07-14 single gate driver opto
    [Gate Driver Chip.PcbDoc, Gate Driver Chip.SchDoc, Motor Driver (Single).PcbDoc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]
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2022-07-15 altium config files
    [SPICEBot.PrjPcb]
2022-07-15 single motor board, top traces
    [Gate Driver Chip.PcbDoc, Motor Driver (Single).PcbDoc, SPICEBot.PrjPcb]
2022-07-16 updated values in IR circuit in altium
    [IR.SchDoc, SPICEBot.PrjPcb]
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2022-07-21 res and pot values in IR and reflectance schems
    [IR.SchDoc, Reflectance.SchDoc]
2022-07-21 namespaces change. Undefined ref issuess
    [main.cpp]
2022-07-21 power updated on schems
    [Bluepill and Power.SchDoc, Rear Motors.SchDoc, Servos.SchDoc]
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2022-07-22 fix pwmChange - wrote TODO (Chris)
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2022-07-22 res values for reflectance circuit
    [BP.PcbDoc, Bluepill and Power.SchDoc, Rear Motors.SchDoc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]
2022-07-22 fixed MotorDriver pwm change flag for dir change, added treasure detection
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2022-07-23 In progress not working
    [ir.cpp, main.cpp]
2022-07-23 file rearrangement
    [SPICEBot.PrjPcb, Servo Opto.SchDoc, Servos.SchDoc]
2022-07-23 fixed first treasure collection code
    [config.h, main.cpp, tape-follower.cpp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]
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2022-07-23 Fixed serial not working with IR
    [ir.cpp, main.cpp]
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2022-07-29 updated IR pins, fixed servo mechanism, added motor driver methods
    [board-setup.cpp, encoder.cpp, ir.cpp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]
2022-07-29 minor schematic changes
    [BP.PcbDoc, Bluepill and Power.SchDoc, Reflectance.SchDoc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]
2022-07-29 fixed encoder cache
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2022-07-31 reverse cache refactor complete
    [encoder.cpp, main.cpp, tape-follower.cpp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]
2022-08-01 fixed bugs in cache actions and added implementation for encoder based motor braking
    [encoder.cpp]
2022-08-01 schematic changes
    [BP.PcbDoc, Bluepill and Power.SchDoc, SPICEBot.PrjPcb]
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2022-08-01 bug fix, updated stop time
    [treasure-detection.cpp]
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2022-08-02 bug fixes & refactorization
    [encoder.cpp]
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2022-08-03 added encoder pulses changed check. may use for stalling
    [encoder.cpp]
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2022-08-04 fixed bugs on findTape refactor
    [executor.cpp, tape-follower.cpp]
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2022-08-07 working 4 treasures but need to fix first front
    [executor.cpp, servo-controller.cpp, tape-follower.cpp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]
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2022-08-10 UPDATED CHANGES w/ FAILSAFE WORKING (but third treasure angle change)
    [executor.cpp, treasure-detection.cpp]
2022-08-10 some tuning, added failsafe for sonar misses (untested)
    [executor.cpp, main.cpp, treasure-detection.cpp]
2022-08-10 bug fix from prev commit
    [treasure-detection.cpp]
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2022-08-11 last run of the night - reverted claw close
    [executor.cpp, treasure-detection.cpp]
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
